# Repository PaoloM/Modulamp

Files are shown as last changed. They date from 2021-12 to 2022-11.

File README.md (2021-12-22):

# Modulamp
A modular concept for a streaming + amplifier box.

## BOM

* Chassis (including transparent window)
* 2x Knobs for volume and mode
* 4x Speaker posts
* 4x RCA inputs
* Raspberry Pi (3B+ or better)
* HifiBerry DAC+ DSP
* Wemos D1 mini
* 5" DSI display
* 0.98" OLED display
* 2x LM3914 bar graph drivers
* 2x 10 segments LED bar graph displays
* 3x 5v relays

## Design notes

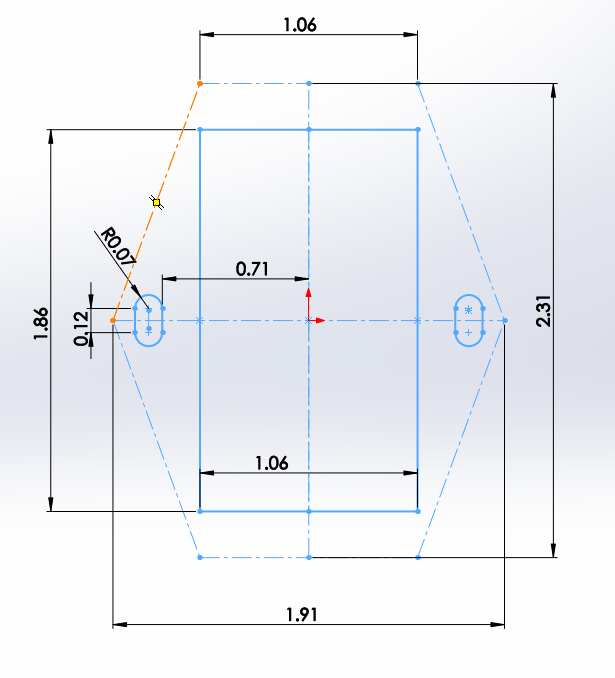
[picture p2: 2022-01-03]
assets/FVJ3S3GIYGFJQC9.png

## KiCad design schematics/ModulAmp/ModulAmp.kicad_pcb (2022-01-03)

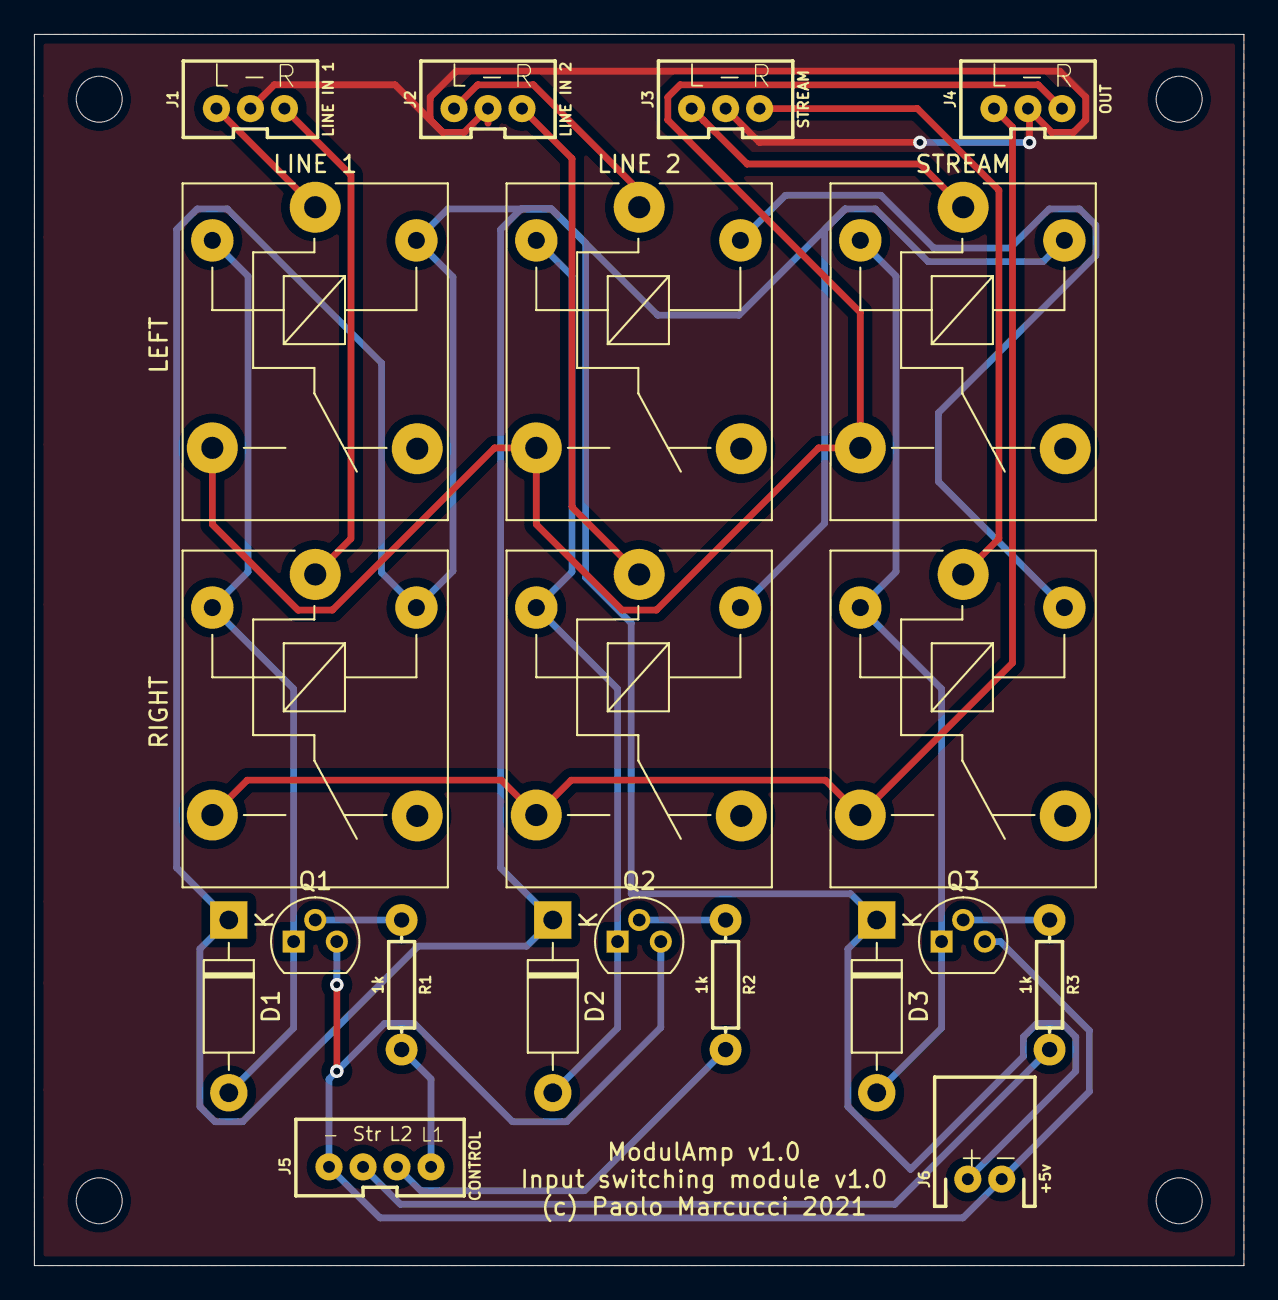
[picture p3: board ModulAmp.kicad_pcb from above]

Board: 2 copper layers, 71.1 x 72.4 mm, 21 parts (0 on the bottom side), 21 nets.

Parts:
D1, D2, D3: 1N4007; D_DO-41_SOD81_P10.16mm_Horizontal
J1: LINE IN 1; JST-3-PTH-VERT
J2: LINE IN 2; JST-3-PTH-VERT
J3: STREAM; JST-3-PTH-VERT
J4: OUT; JST-3-PTH-VERT
J5: CONTROL; JST-4-PTH-VERT
J6: +5v; JST-2-PTH
K3: LINE 2 RIGHT; Relay_SPDT_SANYOU_SRD_Series_Form_C
K4: LINE 2; Relay_SPDT_SANYOU_SRD_Series_Form_C
K5: STREAM RIGHT; Relay_SPDT_SANYOU_SRD_Series_Form_C
K6: STREAM; Relay_SPDT_SANYOU_SRD_Series_Form_C
LEFT: LINE 1; Relay_SPDT_SANYOU_SRD_Series_Form_C
Q1, Q2, Q3: 2N2222A; TO-92
R1, R2, R3: 1k; AXIAL-0.3
RIGHT: LINE 1 RIGHT; Relay_SPDT_SANYOU_SRD_Series_Form_C

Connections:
GNDA: J1.2, J2.2, J3.2, J4.2
GNDD: J5.1, J6.2, Q1.3, Q2.3, Q3.3
unnamed: D1.1, D2.1, D3.1, J6.1, K3.5, K6.5, LEFT.5, RIGHT.5
unnamed: D1.2, LEFT.2, Q1.1, RIGHT.2
unnamed: D2.2, K3.2, K4.2, Q2.1
unnamed: D3.2, K5.2, K6.2, Q3.1
unnamed: J1.1, LEFT.1
unnamed: J1.3, RIGHT.1
unnamed: J2.1, K4.1
unnamed: J2.3, K3.1
unnamed: J3.1, K6.1
unnamed: J3.3, K5.1
unnamed: J4.1, K3.3, K5.3, RIGHT.3
unnamed: J4.3, K4.3, K6.3, LEFT.3
unnamed: J5.2, R3.P$2
unnamed: J5.3, R2.P$2
unnamed: J5.4, R1.P$2
unnamed: K4.5, K5.5
unnamed: Q1.2, R1.P$1
unnamed: Q2.2, R2.P$1
unnamed: Q3.2, R3.P$1

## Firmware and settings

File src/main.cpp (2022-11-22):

// ==========================================================================================
// Jeeves.BoilerPlate
// main.cpp
//
// MIT License
//
// Copyright (c) 2020-2021 Paolo Marcucci
//
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
#define SENSOR_TYPE "ModulAmp" // type of sensor
#define VERSION "1.0"          // firmware version
#define MAIN_TOPIC "modulamp"  // default MQTT topic (can be empty)

#include "main.h"
#include "EEPROM.h"

// Global variables -------------------------------------------------------------------------

// - Fonts
#define HEADER_FONT u8g2_font_logisoso16_tf
#define BODY_FONT u8g2_font_logisoso34_tf

// - Smart knob values
#define KNOB_MODE_MENU 0
#define KNOB_MODE_VOLUME 1
#define KNOB_MODE_INPUT 2

int KNOB_MODE_MENU_MAX = 2;
int KNOB_MODE_MENU_MIN = 1;

#define KNOB_INPUT_STREAM 0
#define KNOB_INPUT_LINE1 1
#define KNOB_INPUT_LINE2 2
#define KNOB_INPUT_BACK 3

int KNOB_MODE_INPUT_MAX = 2;
int KNOB_MODE_INPUT_MIN = 0;

int KNOB_MODE_VOLUME_MAX = 50;
int KNOB_MODE_VOLUME_MIN = 0;

int KNOB_MODE = KNOB_MODE_VOLUME;

int KNOB_MENU = KNOB_MODE_VOLUME;
int KNOB_INPUT = KNOB_INPUT_STREAM;
int KNOB_SELECTED_INPUT = KNOB_INPUT;
int KNOB_VOLUME = KNOB_MODE_VOLUME_MIN;

boolean KNOB_BUTTON_PRESSED = false;

#define DELTA 1

// TODO: add global variables here
int addr = 0;

// MQTT sensor specific topics to report values ---------------------------------------------
char input_mqtt_topic[50];
char volume_mqtt_topic[50];

int input[3]; // Pin related to each input

#define volumeSelectPin 10 /* SS */

// ==========================================================================================
//
// IMPLEMENTATION
//
// ==========================================================================================

// ==========================================================================================
// HW routines
// ==========================================================================================

void selectInput(int value)
{
  KNOB_SELECTED_INPUT = value;
  for (int i = 0; i <= KNOB_MODE_INPUT_MAX; i++)
  {
    if (i == value)
    {
      digitalWrite(input[i], 1);
    }
    else
    {
      digitalWrite(input[i], 0);
    }
  }
}

void setVolume(int value)
{
  int actualValue = 255 * value / KNOB_MODE_VOLUME_MAX;
  if (actualValue <= 0)
    actualValue = 1;

  KNOB_VOLUME = value;
  
  Serial.print("Volume = ");
  Serial.print(KNOB_VOLUME);
  Serial.print(" (");
  Serial.print(actualValue);
  Serial.println(")");

  // Send volume info
  pinMode(volumeSelectPin, LOW);
  SPI.transfer(actualValue); // right channel
  SPI.transfer(actualValue); // left channel
  pinMode(volumeSelectPin, HIGH);
}

void saveVolume(int value)
{
  if (USE_EEPROM)
  {
    EEPROM.put(0, (uint8_t)KNOB_VOLUME);
    EEPROM.commit();
    if (USE_SERIAL)
    {
      Serial.print("Saving volume ");
      Serial.println(KNOB_VOLUME);
    }
  }
}

void saveInput(int value)
{
  if (USE_EEPROM)
  {
    EEPROM.put(1, (uint8_t)KNOB_INPUT);
    EEPROM.commit();
    if (USE_SERIAL)
    {
      Serial.print("Saving input ");
      Serial.println(KNOB_INPUT);
    }
  }
}

int getVolume()
{
  uint8_t v = 0;

  if (USE_EEPROM)
  {
    v = EEPROM.read(0);
    if (USE_SERIAL)
    {
      Serial.print("Reading volume ");
      Serial.println(v);
    }
  }
  return ((int)v);
}

int getInput()
{
  uint8_t v = 0;
  if (USE_EEPROM)
  {
    v = EEPROM.read(1);
    if (USE_SERIAL)
    {
      Serial.print("Reading input ");
      Serial.println(v);
    }
  }
  return ((int)v);
}

void resetScreenTimeout()
{
  screenTimeoutTimer = millis();
  SCREEN_ACTIVE = true;
}

// ------------------------------------------------------------------------------------------
// Step 1/7 - Add any sensor-specific initialization code
// ------------------------------------------------------------------------------------------

void sensorSetup()
{
  char s[80];
  IPAddress ip = WiFi.localIP();

  if (SENSOR_SSD1306) // - SSD1306 I2C OLED DISPLAY
  {
    u8g2.begin();

    // Show splash screen
    u8g2.clearBuffer();
    u8g2.setFont(u8g2_font_helvB12_tr);
    sprintf(s, "%s", SENSOR_TYPE);
    u8g2.drawStr(0, 18, s);
    u8g2.setFont(u8g2_font_profont12_mf);
    sprintf(s, "ID :%06X", DEVICE_ID);
    u8g2.drawStr(0, 32, s);
    sprintf(s, "IP :%u.%u.%u.%u", ip[0], ip[1], ip[2], ip[3]);
    u8g2.drawStr(0, 42, s);
    sprintf(s, "Loc:%s", LOCATION);
    u8g2.drawStr(0, 52, s);
    sprintf(s, "Ver:%s", VERSION);
    u8g2.drawStr(0, 62, s);
    u8g2.sendBuffer();
    // End splash screen

    ON_SPLASH_SCREEN = true;
  }

  if (SENSOR_KY040) // - KY040 ROTARY ENCODER
  {
    pinMode(KY040_PIN_IN1, INPUT);
    pinMode(KY040_PIN_IN1, INPUT_PULLUP);
    pinMode(KY040_PIN_IN2, INPUT);
    pinMode(KY040_PIN_IN2, INPUT_PULLUP);
    pinMode(KY040_PIN_BUTTON, INPUT);
    pinMode(KY040_PIN_BUTTON, INPUT_PULLUP);

    KNOB_MODE = KNOB_MODE_VOLUME;
    KNOB_VOLUME = getVolume();
    KNOB_INPUT = getInput();
  }

  if (USE_EEPROM)
  {
    EEPROM.begin(512);
  }

  input[0] = D0;
  input[1] = 9;  // SD2
  input[2] = 10; // SD3
  for (int i = 0; i <= KNOB_MODE_INPUT_MAX; i++)
  {
    pinMode(input[i], OUTPUT);
    digitalWrite(input[i], 0);
  }
  selectInput(KNOB_INPUT_STREAM);

  // pinMode(volumeSelectPin, OUTPUT);
  // SPI.begin();
}

// ------------------------------------------------------------------------------------------
// Step 2/7 - Setup the MQTT topics
// ------------------------------------------------------------------------------------------
void sensorMqttSetup()
{
  sprintf(input_mqtt_topic, "%s/%s", LOCATION, STR_MODULAMP_TOPIC_INPUT);
  sprintf(volume_mqtt_topic, "%s/%s", LOCATION, STR_MODULAMP_TOPIC_VOLUME);
}

// ------------------------------------------------------------------------------------------
// Step 3a/7 - Read data from the sensor(s) timed every DELAY_MS milliseconds
// ------------------------------------------------------------------------------------------
void sensorUpdateReadings()
{
  // Saving status to EEPROM
  saveVolume(KNOB_VOLUME);
  saveInput(KNOB_SELECTED_INPUT);
}

// ------------------------------------------------------------------------------------------
// Step 3b/7 - Read data from the sensor(s) on every loop
// ------------------------------------------------------------------------------------------
void sensorUpdateReadingsQuick()
{
  if (SENSOR_KY040) // - KY040 rotary encoder readings
  {
    switch (KY040_STATUS_CURRENT)
    {
    case KY040_STATUS_PRESSED:
      // flip between states
      switch (KNOB_MODE)
      {
      case KNOB_MODE_MENU: // select the current menu entry
        KNOB_MODE = KNOB_MENU;
        break;
      case KNOB_MODE_INPUT: // select the input
        KNOB_SELECTED_INPUT = KNOB_INPUT;
        selectInput(KNOB_SELECTED_INPUT);
        KNOB_MODE = KNOB_MODE_VOLUME; // go directly to volume
        break;
      case KNOB_MODE_VOLUME: // go back to the menu
        KNOB_MODE = KNOB_MODE_MENU;
        break;
      default:
        break;
      }

      ON_SPLASH_SCREEN = false;
      resetScreenTimeout();
      sensorUpdateDisplay();
      KY040_STATUS_CURRENT = KY040_STATUS_IDLE;
      break;

    case KY040_STATUS_GOINGUP:
      switch (KNOB_MODE)
      {
      case KNOB_MODE_MENU: // move to the next menu entry
        if (++KNOB_MENU > KNOB_MODE_MENU_MAX)
          KNOB_MENU = KNOB_MODE_MENU_MIN;
        break;
      case KNOB_MODE_INPUT: // move to the next input
        if (++KNOB_INPUT > KNOB_MODE_INPUT_MAX)
          KNOB_INPUT = KNOB_MODE_INPUT_MIN;
        break;
      case KNOB_MODE_VOLUME: // increment the volume
        if (KNOB_VOLUME < KNOB_MODE_VOLUME_MAX)
          KNOB_VOLUME += DELTA;
        setVolume(KNOB_VOLUME);
        break;
      default:
        break;
      }

      ON_SPLASH_SCREEN = false;
      resetScreenTimeout();
      sensorUpdateDisplay();
      KY040_STATUS_CURRENT = KY040_STATUS_IDLE;
      break;

    case KY040_STATUS_GOINGDOWN:
      switch (KNOB_MODE)
      {
      case KNOB_MODE_MENU: // move to the prev menu entry
        if (--KNOB_MENU < KNOB_MODE_MENU_MIN)
          KNOB_MENU = KNOB_MODE_MENU_MAX;
        break;
      case KNOB_MODE_INPUT: // move to the prev input
        if (--KNOB_INPUT < KNOB_MODE_INPUT_MIN)
          KNOB_INPUT = KNOB_MODE_INPUT_MAX;
        break;
      case KNOB_MODE_VOLUME: // decrement the volume
        if (KNOB_VOLUME > KNOB_MODE_VOLUME_MIN)
          KNOB_VOLUME -= DELTA;
        setVolume(KNOB_VOLUME);
        break;
      default:
        break;
      }

      ON_SPLASH_SCREEN = false;
      resetScreenTimeout();
      sensorUpdateDisplay();
      KY040_STATUS_CURRENT = KY040_STATUS_IDLE;
      break;

    default:
      break;
    }
  }
}

// ------------------------------------------------------------------------------------------
// Step 4/7 - Send the values to the MQTT server
// ------------------------------------------------------------------------------------------
void sensorReportToMqtt()
{
  bool emitTimestamp = true;

  sendToMqttTopicAndValue(input_mqtt_topic, String(KNOB_SELECTED_INPUT));
  sendToMqttTopicAndValue(volume_mqtt_topic, String(KNOB_VOLUME));

  if (emitTimestamp) // Common timestamp for all MQTT topics pub
  {
    time_t temp;
    struct tm *timeptr;
    char s[80], t[80];

    temp = time(NULL);
    timeptr = localtime(&temp);

    strftime(s, sizeof(s), "%Y-%m-%d %T", timeptr);
    sprintf(t, "%s/%s", LOCATION, STR_SENSOR_TOPIC_TIMESTAMP);
    sendToMqttTopicAndValue(t, s);
  }
}

// ------------------------------------------------------------------------------------------
// Step 5/7 - Report the latest values to the serial console
// ------------------------------------------------------------------------------------------
void sensorReportToSerial()
{
  if (USE_SERIAL)
  {
    // TODO: report required values to the console
    /* code */
  }
}

// ------------------------------------------------------------------------------------------
// Step 6/7 - Update the local display
// ------------------------------------------------------------------------------------------
void sensorUpdateDisplay()
{
  if (SCREEN_ACTIVE) // update the display only if active
  {
    if (!ON_SPLASH_SCREEN) // update the display only if the splash screen has been dismissed
    {
      if (SENSOR_SSD1306)
      {
        char s[20];
        u8g2.clearBuffer();
        switch (KNOB_MODE)
        {
        // TODO redesign the screens for menu, input, volume
        case KNOB_MODE_MENU:
          u8g2.setFont(HEADER_FONT);
          sprintf(s, "%s", STR_MODULAMP_MENU_HEADER);
          u8g2.drawStr(0, 16, s);

          u8g2.setFont(BODY_FONT);
          switch (KNOB_MENU)
          {
          case KNOB_MODE_INPUT:
            sprintf(s, "%s", STR_MODULAMP_MENU_INPUT);
            break;
          case KNOB_MODE_VOLUME:
            sprintf(s, "%s", STR_MODULAMP_MENU_VOLUME);
            break;
          }
          u8g2.drawStr(0, 60, s);
          break;

        case KNOB_MODE_INPUT:
          u8g2.setFont(HEADER_FONT);
          sprintf(s, "%s", STR_MODULAMP_MENU_INPUT);
          u8g2.drawStr(0, 16, s);

          u8g2.setFont(BODY_FONT);
          switch (KNOB_INPUT)
          {
          case KNOB_INPUT_BACK:
            sprintf(s, "%s", "MENU"); // TODO - is this even a valid state?
            break;
          case KNOB_INPUT_STREAM:
            sprintf(s, "%s", STR_MODULAMP_MENU_INPUT_STREAM);
            break;
          case KNOB_INPUT_LINE1:
            sprintf(s, "%s", STR_MODULAMP_MENU_INPUT_LINE1);
            break;
          case KNOB_INPUT_LINE2:
            sprintf(s, "%s", STR_MODULAMP_MENU_INPUT_LINE2);
            break;
          }
          u8g2.drawStr(0, 60, s);
          break;

        case KNOB_MODE_VOLUME:
          u8g2.setFont(HEADER_FONT);
          sprintf(s, "%s", STR_MODULAMP_MENU_VOLUME);
          u8g2.drawStr(0, 16, s);

          u8g2.setFont(BODY_FONT);
          sprintf(s, "%d", KNOB_VOLUME);
          u8g2.drawStr(0, 60, s);
          break;

        default:
          break;
        }

        u8g2.sendBuffer();
      }

      /* code */ // <-- other indicators and annunciators
    }
  }
  else
  {
    char s[20];

    u8g2.clearBuffer();
    u8g2.setFont(HEADER_FONT);
    switch (KNOB_INPUT)
    {
    case KNOB_INPUT_BACK:
      sprintf(s, "%s", "MENU"); // TODO - is this even a valid state?
      break;
    case KNOB_INPUT_STREAM:
      sprintf(s, "%s", STR_MODULAMP_MENU_INPUT_STREAM);
      break;
    case KNOB_INPUT_LINE1:
      sprintf(s, "%s", STR_MODULAMP_MENU_INPUT_LINE1);
      break;
    case KNOB_INPUT_LINE2:
      sprintf(s, "%s", STR_MODULAMP_MENU_INPUT_LINE2);
      break;
    }
    u8g2.drawStr(0, 40, s);
    u8g2.sendBuffer();
  }
}

// ------------------------------------------------------------------------------------------
// Step 7/7 (optional) - This callback is invoked when an MQTT message is received.
// ------------------------------------------------------------------------------------------
void mqttCallback(char *topic, byte *payload, uint8_t length)
{
  // Prepare message
  String message = "";
  for (int i = 0; i < int(length); i++)
  {
    message += (char)payload[i];
  }

  // log message
  char out[255];
  sprintf(out, STR_MESSAGE_RECEIVED_FORMAT, topic, message.c_str());
  log_out(STR_MQTT_LOG_PREFIX, out);

  // TODO: error handling
  int v;
  char p[255];
  sscanf(message.c_str(), STR_MODULAMP_CMD_FORMAT, p, &v);

  // TODO: make sure it's lowercase
  if (!strcmp(p, STR_MODULAMP_CMD_VOLUME))
    setVolume(v);
  if (!strcmp(p, STR_MODULAMP_CMD_INPUT))
    selectInput(v);
}

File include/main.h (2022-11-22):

// ==========================================================================================
// Jeeves.BoilerPlate
// main.h
//
// MIT License
//
// Copyright (c) 2020-2021 Paolo Marcucci
//
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
#pragma GCC diagnostic ignored "-Wwrite-strings"

#include <Arduino.h>

/*--------------------------- Configuration ------------------------------*/
#include "config.h"                            // Jeeves server address, port
#include "sensor.h"                            // Sensor-specific data
#include "strings.h"

/*--------------------------- Libraries ----------------------------------*/
// External dependencies
#include <Adafruit_Sensor.h>                   // Universal sensor library - adafruit/Adafruit Unified Sensor@^1.1.4
#include <PubSubClient.h>                      // Required for MQTT - knolleary/PubSubClient@^2.8
#include "RestClient.h"                        // Required to access Jeeves services - hal9k-dk/ESP8266 REST client SSL@^2.1.0
#include <DNSServer.h>                         // Required for AP support by tzapu/WiFiManager^0.16.0
#include <ESP8266WebServer.h>                  // Required for AP support by tzapu/WiFiManager^0.16.0
#include <WiFiManager.h>                       // Required for AP support by tzapu/WiFiManager^0.16.0

// Framework dependencies
#include <ESP8266WiFi.h>                       // ESP8266 WiFi driver
#include <ESP8266mDNS.h>
#include <WiFiUdp.h>
#include <ArduinoOTA.h>                        // Required for OTA updates
#include <Wire.h>
#include <SPI.h>
#ifdef USE_SERIAL
#include <SoftwareSerial.h>                    // Allows sensors to avoid the USB serial port
#endif

#include <time.h>

/*--------------------------- Global Variables ---------------------------*/
// MQTT general
const char* STATUS_TOPIC          = "Events";  // MQTT topic to report startup events
char MQTT_BROKER[20];                          // IP address of your MQTT broker
char MQTT_MESSAGE_BUFFER[150];                 // General purpose buffer for MQTT messages
char CMD_TOPIC[50];                            // MQTT topic for receiving commands
char LOCATION[50];                             // Room/area where the sensor is located

// Wifi
#define WIFI_CONNECT_INTERVAL     500          // Wait 500ms intervals for wifi connection
#define WIFI_CONNECT_MAX_ATTEMPTS 10           // Number of attempts/intervals to wait

// General
uint32_t DEVICE_ID;                            // Unique ID from ESP chip ID

// Time/NTP
const char* ntpServer           = "pool.ntp.org";
const long  gmtOffset_sec       = 28800;       //Replace with your GMT offset (seconds)
const int   daylightOffset_sec  = 3600;        //Replace with your daylight offset (seconds)

// Loop timer
unsigned int previousUpdateTime = millis();

unsigned int splashScreenTimer = 0;
bool ON_SPLASH_SCREEN = false;
unsigned int screenTimeoutTimer = 0;
bool SCREEN_ACTIVE = false;

/* ----------------- Hardware-specific config ---------------------- */
/* Serial */
#define     SERIAL_BAUD_RATE      9600         // Speed for USB serial console
#define     ESP_WAKEUP_PIN        D0           // To reset ESP8266 after deep sleep

/*--------------------------- Function Signatures ---------------------------*/
void mqttCallback(char *topic, byte *payload, uint8_t length);
bool initWifi();
void reconnectMqtt();
void sensorReportToMqtt();
void sensorReportToSerial();
void sensorUpdateReadings();
void sensorUpdateReadingsQuick();
void sensorUpdateDisplay();
void sensorSetup();
void sensorMqttSetup();

/*--------------------------- Instantiate Global Objects --------------------*/
WiFiClient                          ESP_CLIENT; // WiFi
PubSubClient                        MQTT_CLIENT(ESP_CLIENT); // MQTT
RestClient                          REST_CLIENT = RestClient(JEEVES_SERVER, JEEVES_SERVER_PORT); // Jeeves server connection
U8G2_SSD1306_128X64_NONAME_F_HW_I2C u8g2(U8G2_R0, 
                                         U8X8_PIN_NONE,
                                         SSD1306_PIN_SCL, 
                                         SSD1306_PIN_SDA);              // All Boards without Reset of the Display

void log_out(char* component, const char* value)
{
  char out[255];
  char s[100];
  time_t temp;
  struct tm *timeptr;

  temp = time(NULL);
  timeptr = localtime(&temp);

  strftime(s,sizeof(s),"%Y-%m-%d %T", timeptr);

  if (DEBUG && USE_SERIAL) {
    sprintf(out, "%s | %s | %s", s, component, value);
    Serial.println(out);
  }
}

void printToSerialTopicAndValue(char* topic, String value)
{
  char out[80];
  sprintf(out, "%s = %s", topic, value.c_str());
  log_out(STR_MQTT_LOG_PREFIX, out);
}

void sendToMqttTopicAndValue(char* topic, String value)
{
  String _value;
  char buffer[255]; // General purpose buffer for MQTT messages

  _value = value;
  _value.toCharArray(buffer, _value.length() + 1);
  MQTT_CLIENT.publish(topic, buffer);
}
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

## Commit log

2021-12-22 First working system, new kicad assets
    [Modulamp 0.1.kicad_pcb, Modulamp 0.1.sch]
2022-01-03 Added kicad files
    [ModulAmp - Amplifier.sch, ModulAmp - Controller.sch, ModulAmp - Input switcher.sch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]
2022-01-03 Added initial schematics
    [ModulAmp - Amplifier.kicad_sch, ModulAmp - Controller.kicad_sch, ModulAmp - Input switcher.kicad_sch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]
2022-01-04 Fixed input mqtt setting
    [main.cpp]
2022-01-08 Refactored strings and added DHTxx full support
    [ModulAmp - Amplifier.kicad_sch, ModulAmp - Controller.kicad_sch, ModulAmp - Input switcher.kicad_sch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]
2022-01-14 Removed DHT config and added current input display
2022-01-28 Added config for EEPROM, new kicad backups
2022-01-31 Updated SSD1306 I2C to use HW
2022-03-09 Working prototype for KY040, SSD1306 and input sel
2022-11-22 Removed DHT sensor
